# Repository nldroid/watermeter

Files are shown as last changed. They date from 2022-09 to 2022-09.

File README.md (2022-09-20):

# Meet je waterverbruik in Home Assistant met behulp van esphome en gratis te printen houders voor je watermeter

Op deze pagina vind je alles wat je nodig hebt om een meter te maken waarmee je in Home Assistant je waterverbuik kunt monitoren.

Voor alle componenten geld dat de Aliexpress versies goedkoper zijn maar dat je er langer op moet wachten voordat je ze in huis hebt. De componenten die je in nederlandse winkels koopt zijn sneller in huis maar duurder.

## Nabijheidsensor LJ18A3-8Z/BX NPN NO 5V
Ik heb in het verleden wel eens geprobeerd om een optische pulse counter te gebruiken voor mijn watermeter maar dat was niet echt een succes. Daarom adviseer ik om een nabijheidsensor te gebruiken.

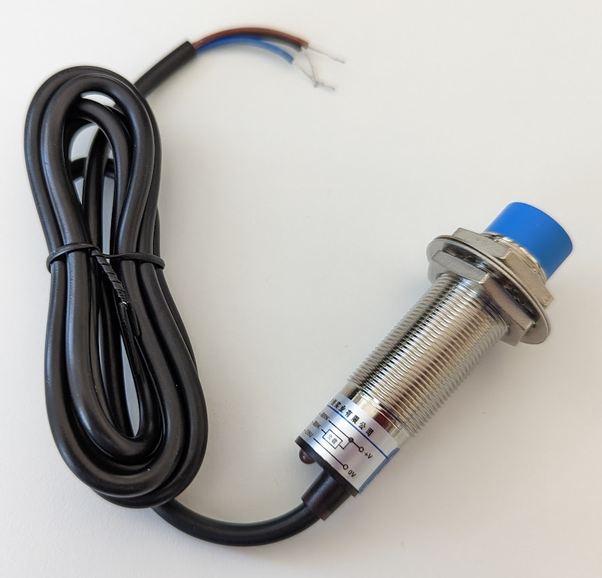
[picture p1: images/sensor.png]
LJ18A3-8Z/BX 5V

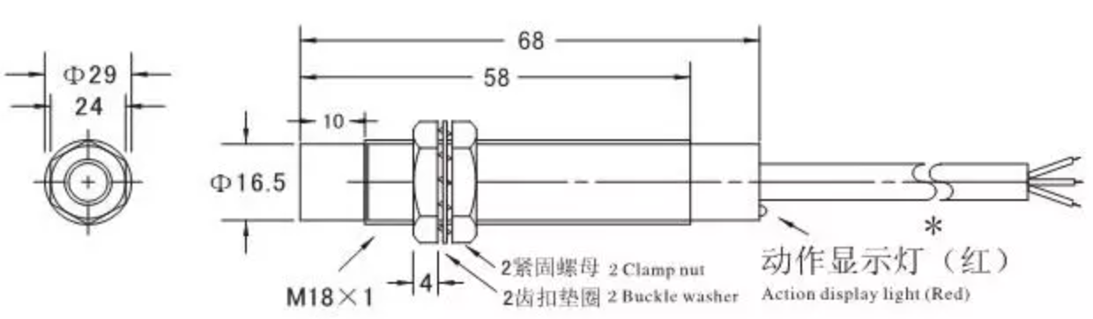
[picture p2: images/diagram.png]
LJ18A3-8Z/BX diagram


Let op dat je de **5 volt** variant koopt en geen andere. Alleen de **5 volt** versie kan direct op je ESP aangesloten worden.

### M18 (18mm diameter)
- Aliexpress: [LJ18A3-8Z/BX 5V](https://nl.aliexpress.com/item/1005001342927135.html)
- Opencircuit: [LJ18A3-8-Z/BX](https://opencircuit.nl/product/lj18a3-8-z-bx-5v-nabijheids-sensor-n-o-npn-8mm)
- Amazon: [LJ18A3-8-Z/BX-5V](https://amzn.to/3xtTYy9) (Affiliate link van Bas)

### M12 (12mm diameter)
- Aliexpress: [LJ12A3-4-Z/BX](https://www.aliexpress.com/item/32553311139.html)

**Let op** als je deze links gebruikt. Ik durf niet te garanderen dat er op een dag een ander type sensor achter de link komt die niet niet op **5 volt** werkt.

Neem de NPN versie. Het maakt niet uit of je een 'Normally Closed' (NC) of 'Normally Opened' (NO) versie koopt omdat we de overgangen tellen.

## ESP
Je kunt elke ESP gebruiken die ondersteund wordt door esphome maar de Wemos D1 mini is een goede optie. Hij is goedkoop en goed verkrijgbaar.

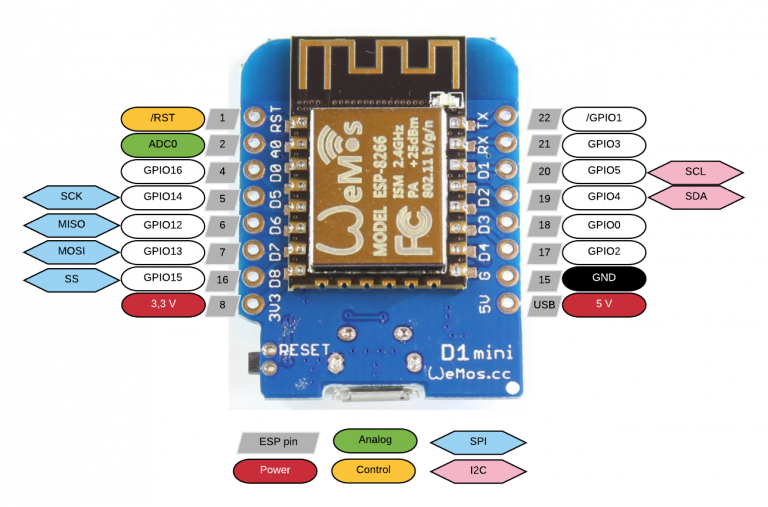
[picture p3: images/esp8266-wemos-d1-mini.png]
Wemos D1 Mini


- Aliexpress: [Wemos D1 mini 3.0 (micro usb)](https://nl.aliexpress.com/item/32651747570.html)
- Aliexpress: [Wemos D1 mini 4.0 (usb-c)](https://nl.aliexpress.com/item/1005004527213280.html)
- Opencircuit: [Wemos D1 mini 4.0 (usb-c)](https://opencircuit.nl/product/wemos-d1-mini-v4.0-wifi-module)

## 3D geprinte houder voor op je watermeter

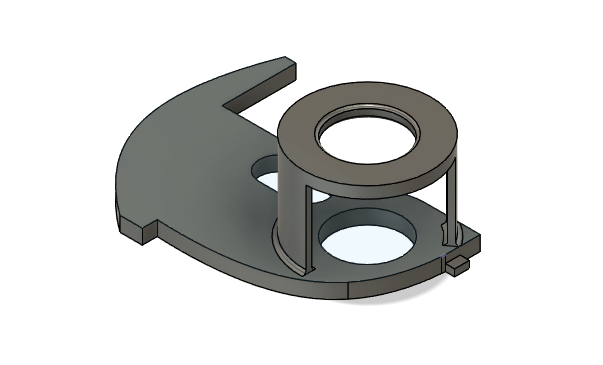
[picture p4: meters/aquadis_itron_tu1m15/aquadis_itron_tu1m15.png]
LJ18A3-8Z/BX


Kijk op de [Meters](meters) pagina of jouw meter er bij staat. Download de files voor je slicer en print je eigen houder.

Als je zelf geen 3D printer hebt, kun je een houder bestellen bij [Bast](https://www.bast-hout.nl/)

## Esphome configuratie

Je kunt [deze esphome configuratie](yaml/watermeter.yaml) gebruiken in esphome. 

## Aansluiten
Sluit de draden van de nabijheidsensor op de volgende manier aan:
- Bruin: 5V
- Blauw: GND
- Zwart: D2/GPIO4 (deze is zo ingesteld in de voorbeeld esphome configuratie)

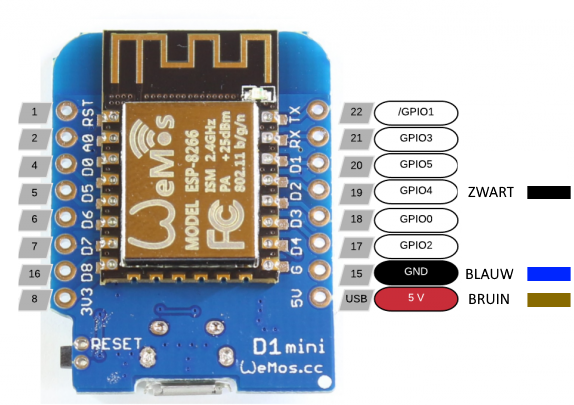
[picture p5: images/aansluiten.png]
Aansluiten Wemos D1


## Meer informatie

- [Pieter Brinkmans blog](https://www.pieterbrinkman.com/2022/02/02/build-a-cheap-water-usage-sensor-using-esphome-home-assistant-and-a-proximity-sensor/)
- [Wouters blog](https://www.twoenter.nl/blog/domotica/watermeter-in-home-assistant-met-esphome/)
- [Installeer esphome in Home Assistant](https://esphome.io/guides/getting_started_hassio.html)
- [Esphome pulse counter](https://esphome.io/components/sensor/pulse_counter.html)
- [Huizebruin blog](https://www.huizebruin.nl/home-assistant/esphome/watermeter-uitlezen-in-home-assistant-met-esphome/_)

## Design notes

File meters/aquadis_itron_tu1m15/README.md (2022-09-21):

# Aquadis Itron tu1m15

Houder voor met monteren van een nabijheidsensor op je Aquadis Itron tu1m15 zodat je je waterverbruik kunt meten in Home Assistant.

## Afbeeldingen
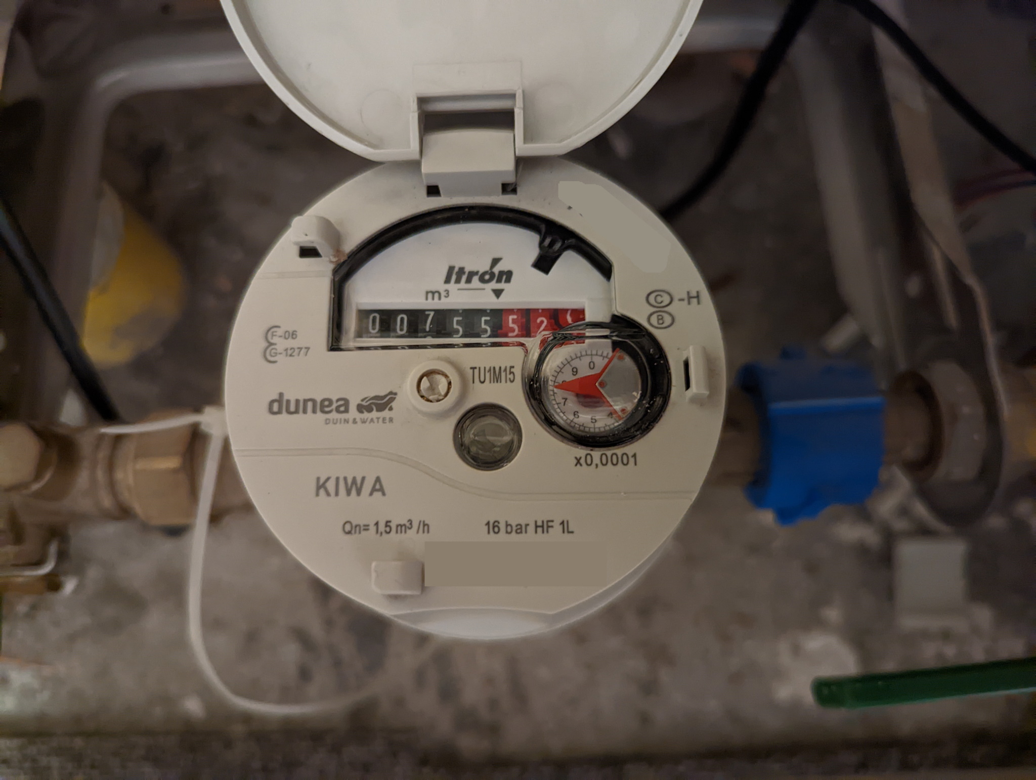
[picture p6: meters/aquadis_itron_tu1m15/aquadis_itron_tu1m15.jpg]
Aquadis Itron tu1m15

Aquadis Itron tu1m15

## 3D print bestanden
- 3D Manufacturing Format: [aquadis_itron_tu1m15.3mf](aquadis_itron_tu1m15.3mf) (gebruik dit in je slicer programma)
- Fusion 360 Archive File: [aquadis_itron_tu1m15.f3d](aquadis_itron_tu1m15.f3d) (gebruik deze als je het ontwerp wil aanpassen in Fusion 360)

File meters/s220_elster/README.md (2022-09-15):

# S220 Elster
Houder voor met monteren van een nabijheidsensor op je S220 Elster water meter zodat je je waterverbruik kunt meten in Home Assistant.

## Afbeeldingen
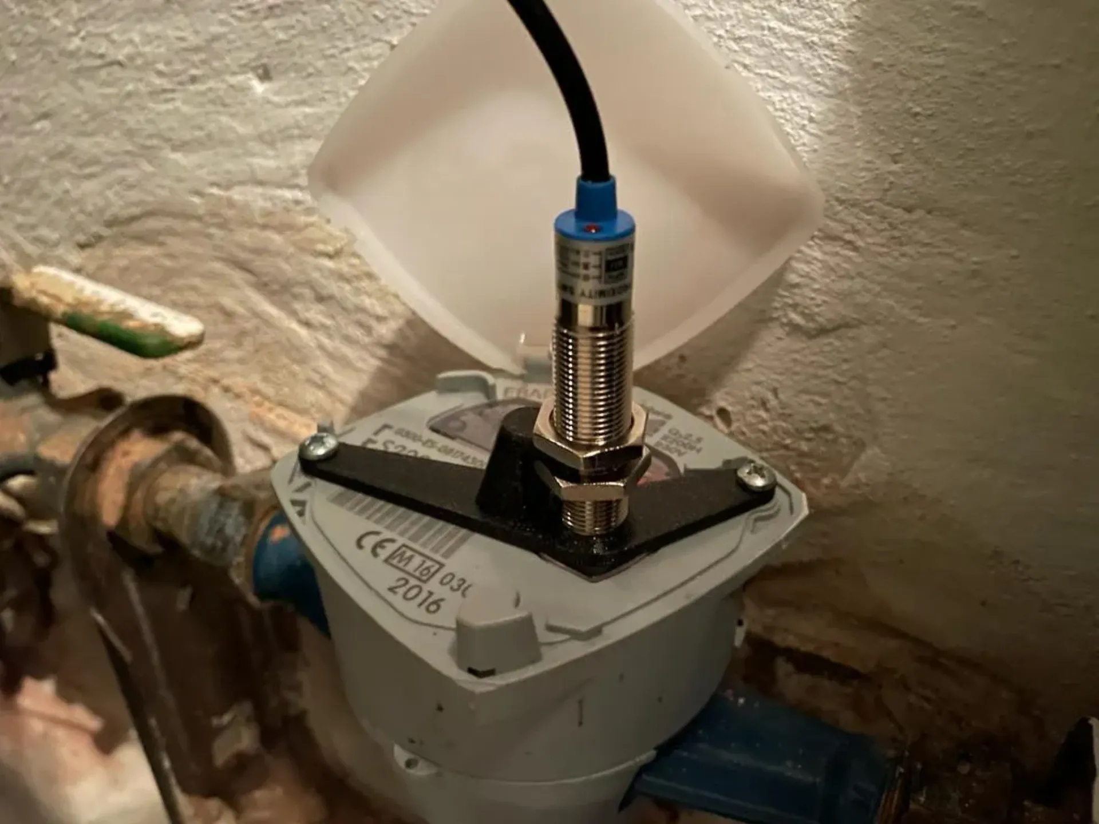
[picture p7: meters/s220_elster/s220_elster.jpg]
S220 Elster


## 3D print bestanden
- STL Format: [s220_elster.stl](s220_elster) (gebruik dit in je slicer programma) (Gekopieerd van [pru-135
](https://www.printables.com/en/model/250995-bracket-s220-elster-watermeter))

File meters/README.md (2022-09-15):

# Collectie van ontwerpen voor houders voor op watermeters

Oke. Oke. Dit is nog niet echt een collectie maar dat zou het kunnen worden. Als je een ontwerp voor een houder voor een specifieke watermeter hebt, kun je die hier bij zetten via een pull request.

## Watermeters

- [Aquadis Itron tu1m15](aquadis_itron_tu1m15)
- [S220 Elster](s220_elster)

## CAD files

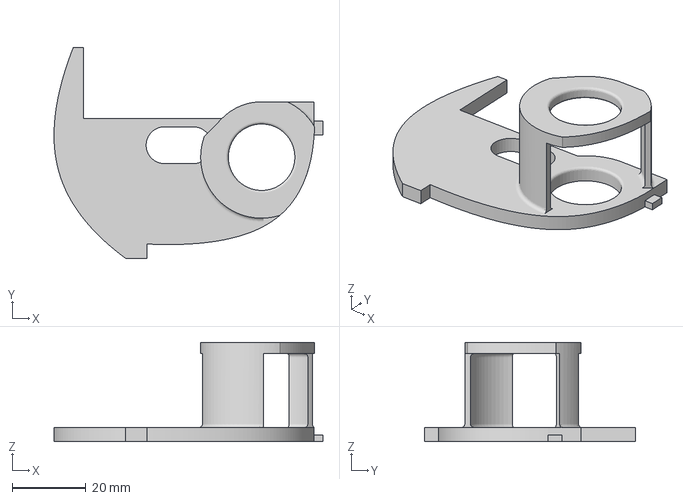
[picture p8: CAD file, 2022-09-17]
meters/aquadis_itron_tu1m15/aquadis_itron_tu1m15.3mf
72.8 x 57.0 x 26.8 mm

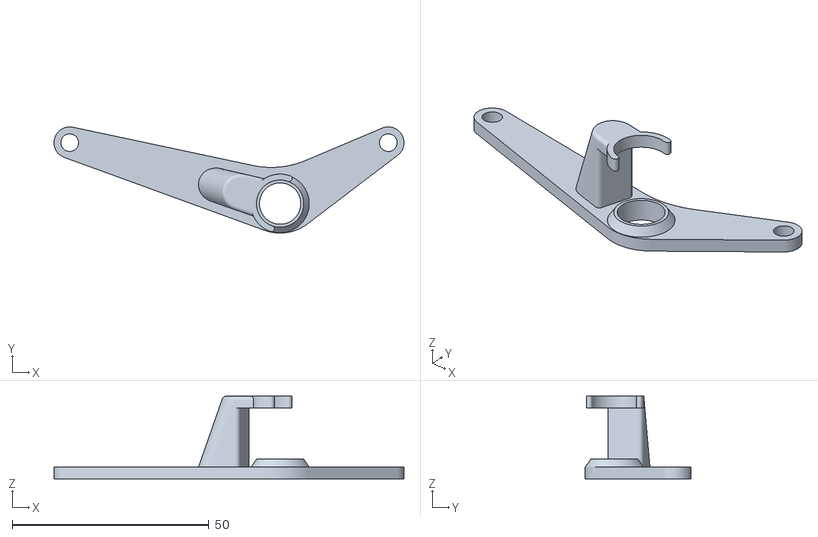
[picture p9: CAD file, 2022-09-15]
meters/s220_elster/s220_elster.stl
89.0 x 27.0 x 21.0

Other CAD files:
meters/aquadis_itron_tu1m15/aquadis_itron_tu1m15.f3d

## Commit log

2022-09-15 First version of the Aquadis meter
    [aquadis_itron_tu1m15.3mf]
2022-09-15 First version
    [aquadis_itron_tu1m15.f3d]
2022-09-15 Updated readme with 3d print files
2022-09-15 Made a list for 3d print files
2022-09-15 Updated dimensions
    [aquadis_itron_tu1m15.f3d]
2022-09-15 Eerste versie
    [s220_elster.stl]
2022-09-15 Missed a bracket
2022-09-16 Nog een Wemos D1 mini 4.0 toegevoegd
2022-09-17 Less support needed
    [aquadis_itron_tu1m15.3mf]
2022-09-17 Info over links verplaatst. M12 sensor toegevoegd.
2022-09-20 Correct link to 5V version
2022-09-20 Extra 5V in de kop
2022-09-21 Added photo of sensor on meter
